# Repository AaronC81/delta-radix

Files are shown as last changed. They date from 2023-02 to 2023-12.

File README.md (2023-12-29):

# Delta Radix

**[Try it online!](https://aaronc81.github.io/delta-radix/)**

The Delta Radix is a desktop calculator designed specifically to be useful for binary and
hexadecimal calculations.

Notable features:

- Mixed binary, hexadecimal, and decimal calculations
- Customisable bit width of arithmetic type (not limited to powers of 2!)
- Support for signed and unsigned data types
- Accurate simulation of overflow 
- Mechanical keyswitches for input

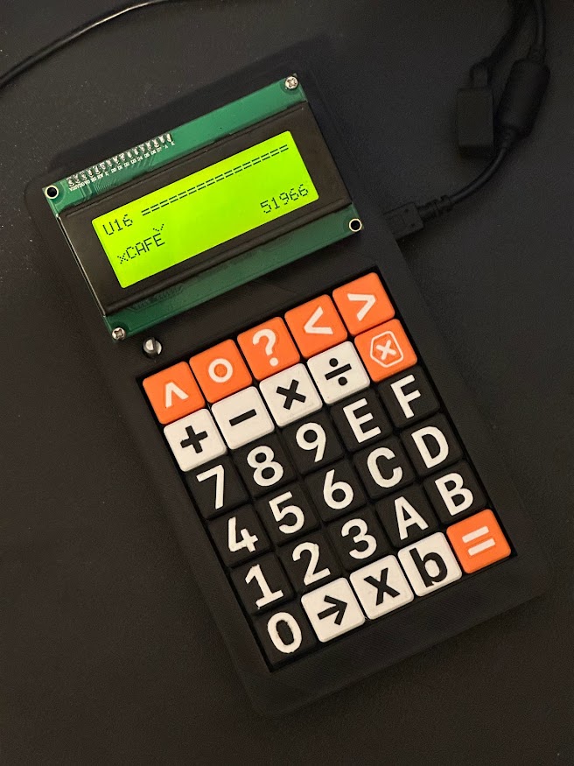
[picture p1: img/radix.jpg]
The Delta Radix calculator, assembled into a black 3D-printed case, with a mixture of black, white, and orange buttons. The black-on-green LCD display is showing the calculation "xCAFE", which evaluates to "51966" in decimal.


## Software

This repository is a Cargo workspace comprising a handful of crates. These are:

- `delta-radix-os` - The user-facing calculator software, 100% hardware-agnostic
- `delta-radix-hal` - Traits which the OS uses to interact with hardware (keypad, display, etc)
- `delta-radix-hal-pico` - Implementation of HAL traits for the Raspberry Pi Pico
- `delta-radix-hal-sim` - Implementation of HAL traits for a simulator which runs in the terminal
- `delta-radix-hal-web` - Implementation of HAL traits for a browser-based simulator with WebAssembly
  (build with `wasm-pack build --target web`, then visit `index.html`)
- `flex-int` - Arbitrary-precision arithmetic library used by the OS

The HAL implementations are the executable targets which should be flashed/run.

Elsewhere, you'll also find:

- [`delta-radix-numworks`](https://github.com/AaronC81/delta-radix-numworks) - Implementation of HAL
  traits for an app on the NumWorks graphing calculator.
  - This is a separate repository because it's not a pure-Cargo project, rather a Rust static
    library linked against a supporting C binary.

## Hardware

`hardware/` contains a KiCad schematic and PCB design.

`cad/` contains a 3D-printable case which the PCB can be mounted into, and keycaps for the switches.

## Usage

**Note:** Arithmetic parsing is incomplete! While they are implemented in the arithmetic library,
there's no way to input operations other than addition yet.

Base specifiers can appear on either site of a number (`xCAFE` or `CAFEx`), whichever you prefer. A
number without a base specifier is always interpreted as a decimal.

To change the result base, press the Format Select (`->`) key and then the base you'd like. Press
the Format Select key twice to return to decimal.

To change the arithmetic data type, use the Menu key. Enter a number of bits, and use the `+`/`-`
keys to choose signed or unsigned respectively.

Shift > Menu shows a menu of meta options, such as entering the bootloader.

## Things left to do

- [X] Faster parsing mode for constant overflow warnings
  - Parsing is slow, largely because of `FlexInt::from_unsigned_decimal_string` 
  - Wouldn't be a problem for evaluation, but is annoying during editing (key-press lag)
  - Either add a faster overall parsing mode just for constant overflow warnings, or versions of 
    number parsing which aren't suitable for evaluation but are fine for warnings (e.g. just use
    built-in Rust parsing, don't calculate overflow)
- [X] "Clear" key (shift + del?)
- [ ] Variables
- [X] Parentheses
- [X] Scrolling expression input
- [X] Show result as if unsigned
- [X] Sleep after inactivity

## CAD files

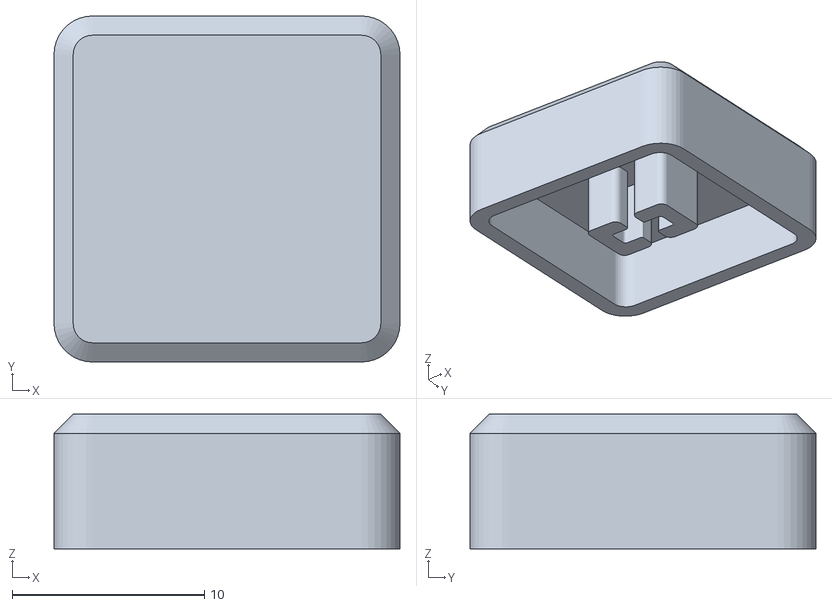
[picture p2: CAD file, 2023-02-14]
cad/keycaps/keycap_base.stl
18.0 x 18.0 x 7.00

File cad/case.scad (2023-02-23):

module fillet(r) {
    difference() {
        square(r);
        translate([r, r]) circle(r, $fn=50);
    }
}

module fillet_corner(r) {
    difference() {
        cube(r);
        translate([r, r, r]) sphere(r, $fn=50);
    }
}

module case_fillets(r) {
    // Edge fillets
    translate([0, case_true_height, 0])
    rotate([90, 0, 0])
    linear_extrude(case_true_height)
    fillet(r);
    
    translate([case_width, case_true_height, 0])
    rotate([90, 270, 0])
    linear_extrude(case_true_height)
    fillet(r);
   
    translate([case_width, 0, 0])
    rotate([0, -90, 0])
    linear_extrude(case_width)
    fillet(r);
    
    translate([case_width, case_true_height, 0])
    rotate([90, 0, 0])
    rotate([0, -90, 0])
    linear_extrude(case_width)
    fillet(r);
    
    // Fillet corners
    fillet_corner(r);
    
    translate([case_width, 0]) rotate([0, 0, 90])
    fillet_corner(r);
    
    translate([case_width, case_true_height]) rotate([0, 0, 180])
    fillet_corner(r);
    
    translate([0, case_true_height]) rotate([0, 0, 270])
    fillet_corner(r);
}

// --------------

calc_width = 100.75 + 0.2;
calc_height = 159.12 + 0.75;

calc_mounting_hole_offset = 4;
calc_mounting_hole_diameter = 2.6; // about right for m3
calc_mounting_hole_depth = 6;

calc_usb_port_from_bottom = 137; // distance to CENTRE
calc_usb_port_width = 15; // be generous for tolerances and/or big cables

calc_mounting_hole_locations = [
    [0, 0],
    [calc_width - calc_mounting_hole_offset * 2, 0],
    [0, calc_height - calc_mounting_hole_offset * 2],
    [calc_width - calc_mounting_hole_offset * 2, calc_height - calc_mounting_hole_offset * 2],
];

calc_pcb_thickness = 1.65;
calc_underneath_thickness = 2.75;

module calc_cutout() {
    translate([0, 0, calc_mounting_hole_depth - calc_underneath_thickness]) {
        difference() {
            linear_extrude(calc_pcb_thickness + calc_underneath_thickness)
            square([calc_width, calc_height]);

            for (loc = calc_mounting_hole_locations) {
                linear_extrude(calc_underneath_thickness)
                translate(loc)
                square([calc_mounting_hole_offset * 2, calc_mounting_hole_offset * 2]);
            }
        }

        for (loc = calc_mounting_hole_locations) {
            translate(concat(loc + [calc_mounting_hole_offset, calc_mounting_hole_offset], -calc_mounting_hole_depth + calc_underneath_thickness))
            linear_extrude(calc_mounting_hole_depth)
            circle(d = calc_mounting_hole_diameter, $fn = 20);
        }
    }
}

calc_cutout_total_thickness = calc_pcb_thickness + calc_mounting_hole_depth;

// ------------


display_mounting_hole_sep_y = 54.5;
display_mounting_hole_sep_x = 93;
display_mounting_hole_diameter = calc_mounting_hole_diameter;

display_post_width = 8;

display_board_width = 98;
display_board_height = 60;

display_tilt_angle = 15;
display_min_height = 7;

display_pin_cutout_width = 45;
display_pin_cutout_height = 5.5;

display_centre_cutout_width = display_board_width - 14;
display_centre_cutout_height = 48;

module display_frame() {
    difference() {
        rotate([display_tilt_angle, 0])
        translate([0, 0, -20]) // arbitrary
        linear_extrude(20 + display_min_height) // arbitrary
        difference() {
            square([display_board_width, display_board_height]);
            
            // Mounting holes
            translate([display_board_width / 2, display_board_height / 2]) {
                for (mul = [[1, 1], [-1, 1], [1, -1], [-1, -1]]) {
                    translate([display_mounting_hole_sep_x * mul[0] / 2, display_mounting_hole_sep_y * mul[1] / 2])
                    circle(d = case_mounting_hole_diameter, $fn = 20);
                }
                
                translate([-display_centre_cutout_width/2, -display_centre_cutout_height/2])
                square([display_centre_cutout_width, display_centre_cutout_height]);
            }
            
            // Pins
            translate([7, display_board_height - display_pin_cutout_height - 0.5])
            square([display_pin_cutout_width, display_pin_cutout_height]);
        }
        
        // All arbitrary, to cut off the bottom
        translate([0, 0, -100])
        linear_extrude(100)
        square([100, 100]);
    }
}

// ------------

case_height = 200;
case_mounting_hole_offset = 5.5;
case_mounting_hole_diameter = 2.6; // about right for m3

bottom_case_mounting_hole_guide_depth = 6;
bottom_case_mounting_hole_guide_diameter = 6;
bottom_case_calc_border = 8;
bottom_case_depth = 2; // not excluding the height of the PCB
bottom_case_true_depth = calc_cutout_total_thickness + bottom_case_depth;

case_width = calc_width + bottom_case_calc_border * 2;
case_true_height = case_height + bottom_case_calc_border * 2;

bottom_case_logo_indent = 2.5;
bottom_case_fillet_radius = 10;

case_mounting_hole_locations = [
    [0, 0],
    [case_width - case_mounting_hole_offset * 2, 0],
    [0, case_true_height - case_mounting_hole_offset * 2],
    [case_width - case_mounting_hole_offset * 2, case_true_height - case_mounting_hole_offset * 2],
];

module logo() {
    translate([-60 / 2, 3 - 50 / 2])
    minkowski() {
        polygon([
            [0, 0],
            [30, 50],
            [60, 0],
            [0, 0.1],
            [60, 0.1],
            [30, 50.1],
            [0, 0.1]
        ]);
        circle(4, $fn=30);
    }
}

module bottom_case() {
    difference() {
        linear_extrude(calc_cutout_total_thickness + bottom_case_depth)
        minkowski() {
            translate([bottom_case_calc_border, bottom_case_calc_border])
            square([calc_width, case_height]);
            
            circle(r = bottom_case_calc_border, $fn = 20);
        }
        
        translate([bottom_case_calc_border, bottom_case_calc_border, bottom_case_depth])
        calc_cutout();
        
        for (loc = case_mounting_hole_locations) {
            translate(loc + [case_mounting_hole_offset, case_mounting_hole_offset])
            linear_extrude(1000) // arbitrary
            circle(d = case_mounting_hole_diameter, $fn = 20);
            
            translate(loc + [case_mounting_hole_offset, case_mounting_hole_offset])
            linear_extrude(bottom_case_mounting_hole_guide_depth)
            circle(d = bottom_case_mounting_hole_guide_diameter, $fn = 20);
        }
        
        translate([bottom_case_calc_border + calc_width, bottom_case_calc_border + calc_usb_port_from_bottom - calc_usb_port_width / 2])
        linear_extrude(100) // arbitrary
        square([bottom_case_calc_border, calc_usb_port_width]);
        
        translate([case_width / 2, case_true_height / 2])
        linear_extrude(bottom_case_logo_indent)
        logo();
        
        case_fillets(bottom_case_fillet_radius);
    }
    
}

// All from the edge of the PCB, not the case
top_case_button_padding_horizontal = 2;
top_case_button_padding_bottom = 7.6;
top_case_button_padding_top = 36; // TODO: needs pot cutout

top_case_mounting_hole_depth = 5;
top_case_rim_depth = 18.3; // should be roughly around the top of keys

top_case_rim_overhang_spacing = 10; // amount of depth until overhangs for key padding

top_case_pot_x = 12.32; // from left
top_case_pot_y = 28.85; // from top
top_case_pot_diameter = 8;

top_case_reset_button_distance_x = 18;
top_case_reset_button_width = 4.3;
top_case_reset_button_height = 3.5;
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

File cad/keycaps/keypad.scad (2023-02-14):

keycap_height = 7;
legend_height = 1.5;
keycap_size = 18;
legend_font_size = 14;

module keycap_with_legend(txt, legend_y_offset=0, legend_x_offset=0) {
    difference() {
        import("keycap_base.stl");

        translate([keycap_size / 2 - .25 + legend_x_offset, (keycap_size - legend_font_size) / 2 + legend_y_offset, keycap_height - legend_height])
        legend(txt, legend_height);
    }
}

module legend(txt, height) {
    linear_extrude(height)
    offset(delta = -0.1)
    text(txt, size = legend_font_size, halign = "center", font = "SF Mono:style=Bold");
}

// ------------------

module number_and_letter_keycaps() {
    s = 25;

    translate([s*0, s*0]) keycap_with_legend("O");

    translate([s*0, s*1]) keycap_with_legend("1");
    translate([s*1, s*1]) keycap_with_legend("2");
    translate([s*2, s*1]) keycap_with_legend("3");

    translate([s*0, s*2]) keycap_with_legend("4");
    translate([s*1, s*2]) keycap_with_legend("5");
    translate([s*2, s*2]) keycap_with_legend("6");

    translate([s*0, s*3]) keycap_with_legend("7");
    translate([s*1, s*3]) keycap_with_legend("8");
    translate([s*2, s*3]) keycap_with_legend("9");

    translate([s*1, s*0]) keycap_with_legend("A");
    translate([s*2, s*0]) keycap_with_legend("B");
    translate([s*3, s*0]) keycap_with_legend("C");
    translate([s*3, s*1]) keycap_with_legend("D");
    translate([s*3, s*2]) keycap_with_legend("E");
    translate([s*3, s*3]) keycap_with_legend("F");
}

module number_and_letter_legends() {
    s = 18;
    h = legend_height - 0.2;
    
    translate([s*0, s*0]) legend("O", h);

    translate([s*0, s*1]) legend("1", h);
    translate([s*1, s*1]) legend("2", h);
    translate([s*2, s*1]) legend("3", h);

    translate([s*0, s*2]) legend("4", h);
    translate([s*1, s*2]) legend("5", h);
    translate([s*2, s*2]) legend("6", h);

    translate([s*0, s*3]) legend("7", h);
    translate([s*1, s*3]) legend("8", h);
    translate([s*2, s*3]) legend("9", h);

    translate([s*1, s*0]) legend("A", h);
    translate([s*2, s*0]) legend("B", h);
    translate([s*3, s*0]) legend("C", h);
    translate([s*3, s*1]) legend("D", h);
    translate([s*3, s*2]) legend("E", h);
    translate([s*3, s*3]) legend("F", h);
}

// ------------------

module operator_keycaps() {
    s = 25;

    translate([s*0, s*0]) keycap_with_legend("+", 1);
    translate([s*1, s*0]) keycap_with_legend("−", 1);
    translate([s*2, s*0]) keycap_with_legend("×", 1);
    translate([s*3, s*0]) keycap_with_legend("÷", 1);
    
    translate([s*0, s*1]) keycap_with_legend("x", 1.7);
    translate([s*1, s*1]) keycap_with_legend("b", 0);
    translate([s*2, s*1]) keycap_with_legend("→", 0, 0.3);
}

module operator_legends() {
    s = 18;
    h = legend_height - 0.2;

    translate([s*0, s*0]) legend("+", h);
    translate([s*1, s*0]) legend("−", h);
    translate([s*2, s*0]) legend("×", h);
    translate([s*3, s*0]) legend("÷", h);
    
    translate([s*0, s*1]) legend("x", h);
    translate([s*1, s*1]) legend("b", h);
    translate([s*2, s*1]) legend("→", h);
}

// ------------------

// TODO
module special_keycaps() {
    s = 25;

    translate([s*0, s*0]) keycap_with_legend("^", -3); // Shift
    translate([s*2, s*1]) keycap_with_legend("=", 1);  // Exe
    translate([s*1, s*0]) keycap_with_legend("◦", 1);  // Menu

    translate([s*0, s*1]) keycap_with_legend("<", 1);  // Left
    translate([s*1, s*1]) keycap_with_legend(">", 1);  // Right
    
    translate([s*2, s*0]) keycap_with_legend("⌫", 0);  // Del
    
    translate([s*3, s*0]) keycap_with_legend("?", 0);  // Var
}

module special_legends() {
    s = 18;
    h = legend_height - 0.2;

    //translate([s*0, s*0]) legend("^", h); // Shift
    //translate([s*2, s*1]) legend("=", h);  // Exe
    //translate([s*1, s*0]) legend("◦", h);  // Menu

    translate([s*0, s*1]) legend("<", h);  // Left
    translate([s*1, s*1]) legend(">", h);  // Right
    
    //translate([s*2, s*0]) legend("⌫", h);  // Del
    
    //translate([s*3, s*0]) legend("?", h);  // Var
}

special_legends();

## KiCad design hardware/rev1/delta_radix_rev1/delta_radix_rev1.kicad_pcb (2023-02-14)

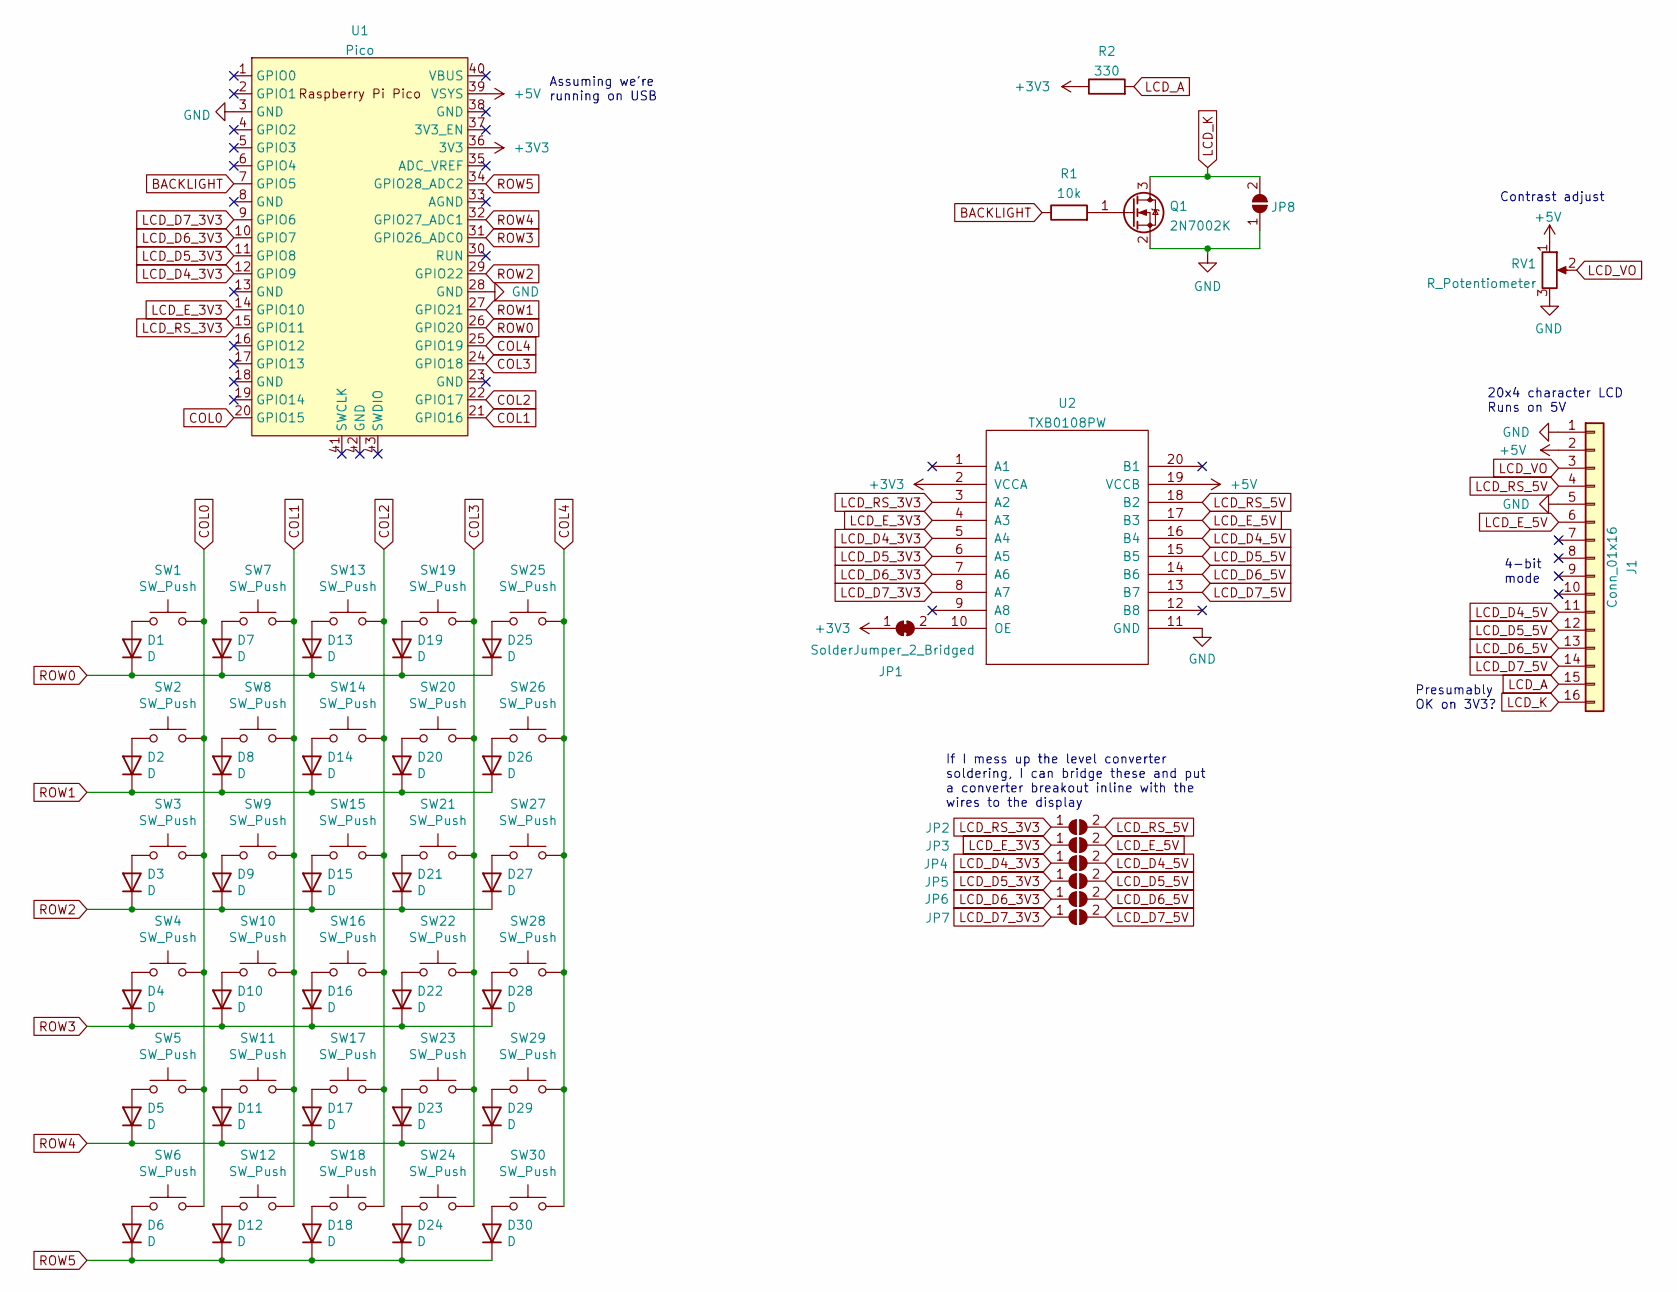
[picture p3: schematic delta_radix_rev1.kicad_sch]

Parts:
D1, D2, D3, D4, D5, D6, D7, D8, D9, D10, D11, D12, D13, D14, D15, D16, D17, D18, D19, D20, D21, D22, D23, D24, D25, D26, D27, D28, D29, D30: D; D_SOD-123
J1: Conn_01x16; PinHeader_1x16_P2.54mm_Vertical
JP1: SolderJumper_2_Bridged; SolderJumper-2_P1.3mm_Bridged_RoundedPad1.0x1.5mm
JP2, JP3, JP4, JP5, JP6, JP7, JP8: SolderJumper_2_Open; SolderJumper-2_P1.3mm_Open_RoundedPad1.0x1.5mm
Q1: 2N7002K; SOT-23_Handsoldering
R1: 10k; R_0603_1608Metric_Pad0.98x0.95mm_HandSolder
R2: 330; R_0603_1608Metric_Pad0.98x0.95mm_HandSolder
RV1: R_Potentiometer; Potentiometer_Alpha_RD901F-40-00D_Single_Vertical_CircularH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
SW1, SW2, SW3, SW4, SW5, SW6, SW7, SW8, SW9, SW10, SW11, SW12, SW13, SW14, SW15, SW16, SW17, SW18, SW19, SW20, SW21, SW22, SW23, SW24, SW25, SW26, SW27, SW28, SW29, SW30: SW_Push; SW_Cherry_MX_1.00u_PCB
U1: Pico; RPi_Pico_SMD_TH
U2: TXB0108PW; TSSOP-20_4.4x6.5mm_P0.65mm

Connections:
+3V3: JP1.1 (A), R2.1, U1.36 (3V3), U2.2 (VCCA)
+5V: J1.2, RV1.1, U1.39 (VSYS), U2.19 (VCCB)
BACKLIGHT: R1.1, U1.7 (GPIO5)
COL0: SW1.2, SW2.2, SW3.2, SW4.2, SW5.2, SW6.2, U1.20 (GPIO15)
COL1: SW7.2, SW8.2, SW9.2, SW10.2, SW11.2, SW12.2, U1.21 (GPIO16)
COL2: SW13.2, SW14.2, SW15.2, SW16.2, SW17.2, SW18.2, U1.22 (GPIO17)
COL3: SW19.2, SW20.2, SW21.2, SW22.2, SW23.2, SW24.2, U1.24 (GPIO18)
COL4: SW25.2, SW26.2, SW27.2, SW28.2, SW29.2, SW30.2, U1.25 (GPIO19)
GND: J1.1, J1.5, JP8.1 (A), Q1.2 (S), RV1.3, U1.3 (GND), U1.28 (GND), U2.11 (GND)
LCD_A: J1.15, R2.2
LCD_D4_3V3: JP4.1 (A), U1.12 (GPIO9), U2.5 (A4)
LCD_D4_5V: J1.11, JP4.2 (B), U2.16 (B4)
LCD_D5_3V3: JP5.1 (A), U1.11 (GPIO8), U2.6 (A5)
LCD_D5_5V: J1.12, JP5.2 (B), U2.15 (B5)
LCD_D6_3V3: JP6.1 (A), U1.10 (GPIO7), U2.7 (A6)
LCD_D6_5V: J1.13, JP6.2 (B), U2.14 (B6)
LCD_D7_3V3: JP7.1 (A), U1.9 (GPIO6), U2.8 (A7)
LCD_D7_5V: J1.14, JP7.2 (B), U2.13 (B7)
LCD_E_3V3: JP3.1 (A), U1.14 (GPIO10), U2.4 (A3)
LCD_E_5V: J1.6, JP3.2 (B), U2.17 (B3)
LCD_K: J1.16, JP8.2 (B), Q1.3 (D)
LCD_RS_3V3: JP2.1 (A), U1.15 (GPIO11), U2.3 (A2)
LCD_RS_5V: J1.4, JP2.2 (B), U2.18 (B2)
LCD_VO: J1.3, RV1.2
unnamed: D1.2 (A), SW1.1
unnamed: D2.2 (A), SW2.1
unnamed: D3.2 (A), SW3.1
unnamed: D4.2 (A), SW4.1
unnamed: D5.2 (A), SW5.1
unnamed: D6.2 (A), SW6.1
unnamed: D7.2 (A), SW7.1
unnamed: D8.2 (A), SW8.1
unnamed: D9.2 (A), SW9.1
unnamed: D10.2 (A), SW10.1
unnamed: D11.2 (A), SW11.1
unnamed: D12.2 (A), SW12.1
unnamed: D13.2 (A), SW13.1
unnamed: D14.2 (A), SW14.1
unnamed: D15.2 (A), SW15.1
unnamed: D16.2 (A), SW16.1
unnamed: D17.2 (A), SW17.1
unnamed: D18.2 (A), SW18.1
unnamed: D19.2 (A), SW19.1
unnamed: D20.2 (A), SW20.1
unnamed: D21.2 (A), SW21.1
unnamed: D22.2 (A), SW22.1
unnamed: D23.2 (A), SW23.1
unnamed: D24.2 (A), SW24.1
unnamed: D25.2 (A), SW25.1
unnamed: D26.2 (A), SW26.1
unnamed: D27.2 (A), SW27.1
unnamed: D28.2 (A), SW28.1
unnamed: D29.2 (A), SW29.1
unnamed: D30.2 (A), SW30.1
unnamed: JP1.2 (B), U2.10 (OE)
unnamed: Q1.1 (G), R1.2
ROW0: D1.1 (K), D7.1 (K), D13.1 (K), D19.1 (K), D25.1 (K), U1.26 (GPIO20)
ROW1: D2.1 (K), D8.1 (K), D14.1 (K), D20.1 (K), D26.1 (K), U1.27 (GPIO21)
ROW2: D3.1 (K), D9.1 (K), D15.1 (K), D21.1 (K), D27.1 (K), U1.29 (GPIO22)
ROW3: D4.1 (K), D10.1 (K), D16.1 (K), D22.1 (K), D28.1 (K), U1.31 (GPIO26_ADC0)
ROW4: D5.1 (K), D11.1 (K), D17.1 (K), D23.1 (K), D29.1 (K), U1.32 (GPIO27_ADC1)
ROW5: D6.1 (K), D12.1 (K), D18.1 (K), D24.1 (K), D30.1 (K), U1.34 (GPIO28_ADC2)

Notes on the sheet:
Contrast adjust
Presumably OK on 3V3?
4-bit mode
If I mess up the level converter soldering, I can bridge these and put a converter breakout inline with the wires to the display
20x4 character LCD Runs on 5V
Assuming we're running on USB

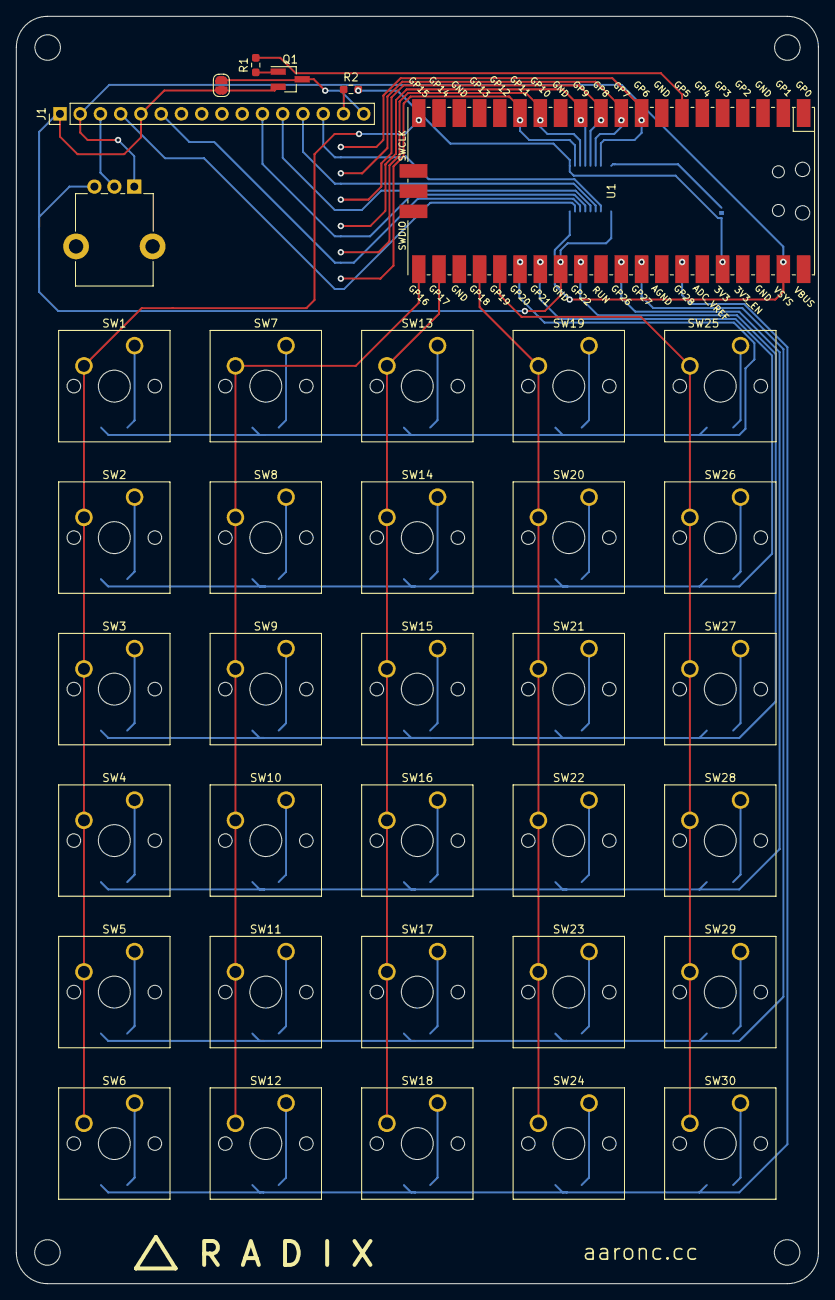
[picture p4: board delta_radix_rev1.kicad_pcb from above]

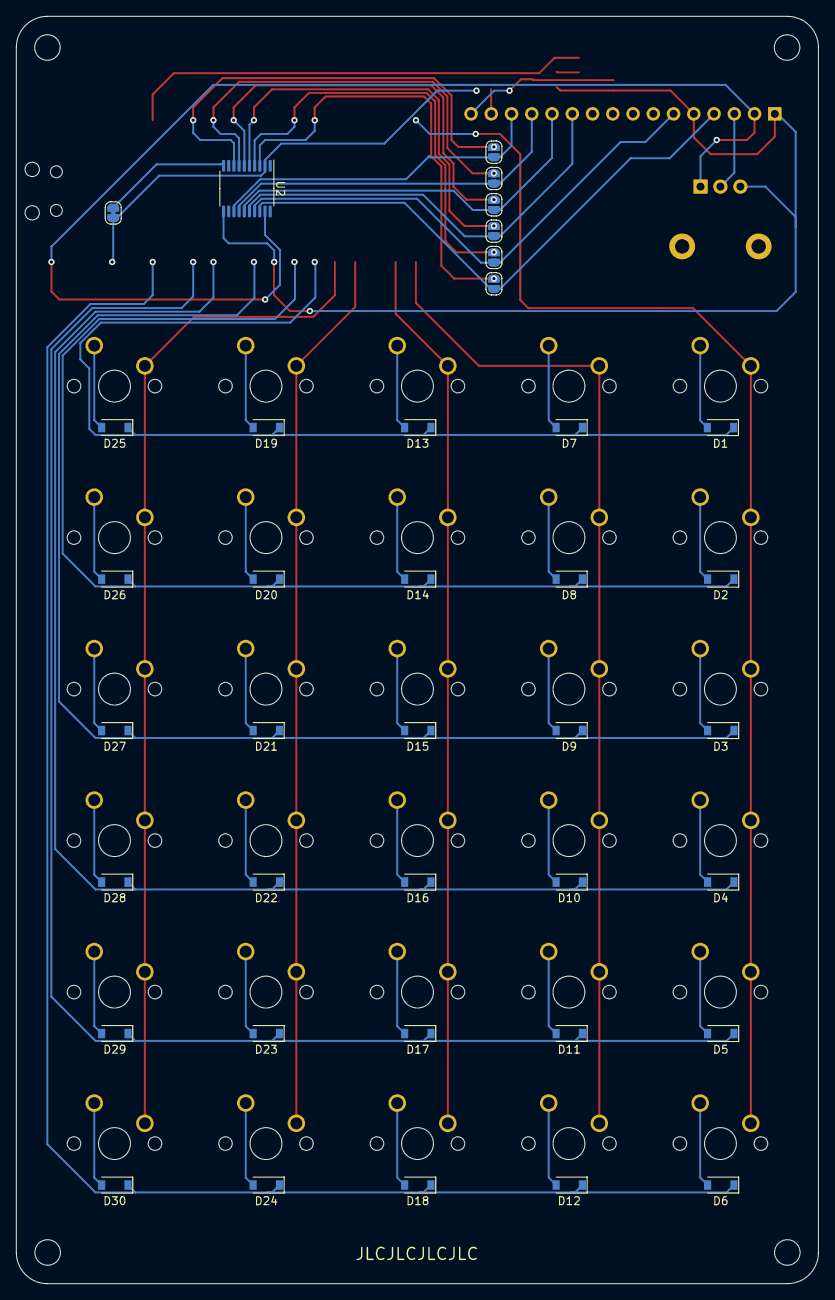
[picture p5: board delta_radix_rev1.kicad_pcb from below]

Board: 2 copper layers, 100.6 x 159.0 mm, 75 parts (38 on the bottom side), 62 nets.

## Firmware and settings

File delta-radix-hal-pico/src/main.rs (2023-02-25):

#![no_std]
#![no_main]
#![feature(alloc_error_handler)]
#![feature(generic_const_exprs)]
#![feature(async_fn_in_trait)]

use alloc_cortex_m::CortexMHeap;
use cortex_m_rt::entry;
use delta_radix_hal::Key;
use embedded_hal::digital::v2::OutputPin;
use hal::{PicoHal, async_keypad::{async_keypad_core1, AsyncKeypadReceiver, ASYNC_KEYPAD_START_MAGIC}};
use hd44780_driver::HD44780;
use panic::init_panic_hal;
use rp_pico::{hal::{Watchdog, Sio, clocks::init_clocks_and_plls, Clock, multicore::{Stack, Multicore}}, pac, Pins};
use embedded_time::{fixed_point::FixedPoint};

extern crate alloc;

mod hal;
mod panic;
mod executor;

fn lives_forever<T: ?Sized>(t: &mut T) -> &'static mut T {
    unsafe { (t as *mut T).as_mut().unwrap() }
}

#[global_allocator]
static ALLOCATOR: CortexMHeap = CortexMHeap::empty();
const HEAP_SIZE: usize = 230_000;

static mut CORE1_STACK: Stack<4096> = Stack::new();

#[entry]
fn main() -> ! {
    // Set up allocator
    {
        use core::mem::MaybeUninit;
        static mut HEAP: [MaybeUninit<u8>; HEAP_SIZE] = [MaybeUninit::uninit(); HEAP_SIZE];
        unsafe {
            ALLOCATOR.init(HEAP.as_ptr() as usize, HEAP_SIZE)
        }
    }

    let mut pac = pac::Peripherals::take().unwrap();
    let core = pac::CorePeripherals::take().unwrap();
    let mut watchdog = Watchdog::new(pac.WATCHDOG);
    let mut sio = Sio::new(pac.SIO);

    let mut mc = Multicore::new(&mut pac.PSM, &mut pac.PPB, &mut sio);
    let cores = mc.cores();
    let core1 = &mut cores[1];
    let _test = core1.spawn(async_keypad_core1, unsafe { &mut CORE1_STACK.mem });

    // External high-speed crystal on the pico board is 12Mhz
    let external_xtal_freq_hz = 12_000_000u32;
    let clocks = init_clocks_and_plls(
        external_xtal_freq_hz,
        pac.XOSC,
        pac.CLOCKS,
        pac.PLL_SYS,
        pac.PLL_USB,
        &mut pac.RESETS,
        &mut watchdog,
    )
        .ok()
        .unwrap();

    let mut delay = cortex_m::delay::Delay::new(core.SYST, clocks.system_clock.freq().integer());

    let pins = Pins::new(
        pac.IO_BANK0,
        pac.PADS_BANK0,
        sio.gpio_bank0,
        &mut pac.RESETS,
    );
    let mut led = pins.led.into_push_pull_output();

    let mut backlight = pins.gpio5.into_push_pull_output();
    backlight.set_high().unwrap();

    // const int rs = 11, en = 10, d4 = 9, d5 = 8, d6 = 7, d7 = 6;
    let rs = pins.gpio11.into_push_pull_output();
    let en = pins.gpio10.into_push_pull_output();
    let d4 = pins.gpio9.into_push_pull_output();
    let d5 = pins.gpio8.into_push_pull_output();
    let d6 = pins.gpio7.into_push_pull_output();
    let d7 = pins.gpio6.into_push_pull_output();
    
    let lcd = HD44780::new_4bit(rs, en, d4, d5, d6, d7, &mut delay).unwrap();

    let mut hal = PicoHal {
        display: hal::LcdDisplay { lcd, delay: lives_forever(&mut delay), backlight },
        keypad: AsyncKeypadReceiver {
            fifo: lives_forever(&mut sio.fifo),
        },
        time: hal::DelayTime { delay: lives_forever(&mut delay) },
    };
    init_panic_hal(lives_forever(&mut hal));

    // Tell the other core to get going
    sio.fifo.write(ASYNC_KEYPAD_START_MAGIC);    

    executor::execute(delta_radix_os::main(&mut hal));
    
    loop {
        led.set_high().unwrap();
        delay.delay_ms(1000);
        led.set_low().unwrap();
        delay.delay_ms(1000);
    }
}

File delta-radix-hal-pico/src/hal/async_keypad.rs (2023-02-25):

use delta_radix_hal::{Key, Keypad, Display};
use embedded_hal::digital::v2::OutputPin;
use embedded_time::duration::{Extensions, Duration, Seconds, Microseconds};
use rp_pico::{pac::{self, interrupt}, hal::{Sio, multicore::Stack, sio::SioFifo, timer::Alarm0, Timer}, Pins};

use crate::{lives_forever, executor, panic::get_panic_hal};

use super::ButtonMatrix;

pub struct AsyncKeypadReceiver<'s> {
    pub fifo: &'s mut SioFifo,
}

impl<'s> delta_radix_hal::Keypad for AsyncKeypadReceiver<'s> {
    async fn wait_key(&mut self) -> Key {
        let hal = get_panic_hal();

        loop {
            let message = self.fifo.read_blocking();

            if message == ASYNC_KEYPAD_SLEEP_MAGIC {
                hal.display.clear();
                hal.display.backlight.set_low().unwrap();

                return Key::Sleep;
            }

            if let Some(key) = Key::from_u32(message) {
                hal.display.backlight.set_high().unwrap();
                return key;
            }
        }
    }
}

pub const ASYNC_KEYPAD_START_MAGIC: u32 = 0xCAFECAFE;
pub const ASYNC_KEYPAD_SLEEP_MAGIC: u32 = 0x00BEDBED;

pub const SLEEP_TIME: Microseconds = Microseconds(120_000_000);

pub fn async_keypad_core1() -> ! {
    // Grab some important peripherals
    let mut pac = unsafe { pac::Peripherals::steal() };
    let core = unsafe { pac::CorePeripherals::steal() };
    let mut sio = Sio::new(pac.SIO);
    let mut delay = cortex_m::delay::Delay::new(core.SYST, 125_000_000);
    let pins = Pins::new(
        pac.IO_BANK0,
        pac.PADS_BANK0,
        sio.gpio_bank0,
        &mut pac.RESETS,
    );

    // Wait until the magic word over FIFO
    loop {
        if sio.fifo.read_blocking() == ASYNC_KEYPAD_START_MAGIC {
            break;
        }
    }

    // Set up button matrix
    let mut matrix = ButtonMatrix {
        delay: lives_forever(&mut delay),

        col0: pins.gpio15.into_pull_up_input(),
        col1: pins.gpio16.into_pull_up_input(),
        col2: pins.gpio17.into_pull_up_input(),
        col3: pins.gpio18.into_pull_up_input(),
        col4: pins.gpio19.into_pull_up_input(),

        row0: pins.gpio20.into_push_pull_output(),
        row1: pins.gpio21.into_push_pull_output(),
        row2: pins.gpio22.into_push_pull_output(),
        row3: pins.gpio26.into_push_pull_output(),
        row4: pins.gpio27.into_push_pull_output(),
        row5: pins.gpio28.into_push_pull_output(),

        currently_pressed: None,
    };

    // Set up timer stuff
    unsafe { pac::NVIC::unmask(pac::Interrupt::TIMER_IRQ_0); }
    let mut timer = Timer::new(pac.TIMER, &mut pac.RESETS);
    let mut alarm = timer.alarm_0().unwrap();
    
    // For the rest of time, loop looking for buttons
    loop {
        // Set up inactivity timer
        alarm.disable_interrupt();
        alarm.schedule(SLEEP_TIME).unwrap();
        alarm.enable_interrupt();
    
        // Wait for press
        let key = executor::execute(matrix.wait_key());
        sio.fifo.write(key.to_u32());
    }
}

#[interrupt]
fn TIMER_IRQ_0() {
    let mut pac = unsafe { pac::Peripherals::steal() };
    let mut sio = Sio::new(pac.SIO);

    // Let the other core know to put the display into a sleep state
    sio.fifo.write(ASYNC_KEYPAD_SLEEP_MAGIC);

    let mut timer = Timer::new(pac.TIMER, &mut pac.RESETS);
    let mut alarm = timer.alarm_0().unwrap();
    alarm.clear_interrupt();
}

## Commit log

2023-01-25 Add delta-radix-hal-pico project
2023-01-25 Implement basics of HAL for Pico
    Gets to a mangled version of the "Press a key" screen!
2023-01-27 Fix display position setting
    [hal.rs]
2023-01-27 "Fix" cursor appearance on hardware
    [display.rs]
2023-01-27 Add bootloader button
2023-01-30 Use own fork of hd44780-driver
2023-01-30 Init the screen correctly
    [display.rs]
2023-01-31 Exclude /cad until I've tidied it up a bit
2023-02-14 Add case models
    [case.scad, keycap_base.stl, keypad.scad]
2023-02-14 Add KiCad design
    [delta_radix_rev1.kicad_pcb, delta_radix_rev1.kicad_sch]
2023-02-15 Attempt to bind HAL to JS functions
    Fails to compile right now for some reason!
    [hal.rs]
2023-02-15 All buttons, and *style*
2023-02-16 Fix some clippy lints
    [hal.rs]
2023-02-16 Fix rust-analyser error, fix more warnings
    [main.rs]
2023-02-17 Better parse error messages
    [display.rs]
2023-02-18 Add a cleaner way of doing keys, new test case
2023-02-21 Fillets, tolerance tweaks, and logo for bottom case
    [case.scad]
2023-02-22 Add fillet to top case
    [case.scad]
2023-02-22 Add reset button hole
    [case.scad]
2023-02-22 Cut out chunk around the display to save filament
    [case.scad]
2023-02-22 Re-enable multicore with smaller heap
    Seems to magically fix things!
    [main.rs]
2023-02-23 Use new executor, wait for special message before starting
    I've figured out where the problem is, at least...
    (Because I can now see the panic message!)
    alloc-cortex-m uses `RefCell`s so we can't alloc in two cores simultaneously
    It's not trivial to remove allocations because `async_trait` desugars to `Box<Pin<...>>`
    Might need a different allocator :(
    [async_keypad.rs, main.rs]
2023-02-23 Use nightly async traits, with no box allocation - now working!
    Also changed a heap pin to a stack pin in async_keypad.rs
    Still need to migrate other HAL crates over to native async traits
2023-02-23 Add BOOTSEL pusher
    [case.scad]
2023-02-23 Fix tests by adding async_fn_in_trait attribute
    [hal.rs]
2023-02-25 Shift+0 to insert parens
    Don't parse yet
2023-02-25 Use * instead of unicode multiply for glyph print default
    So it's only one byte
2023-02-25 Add multiply symbol for Pico
2023-02-25 Add result-signedness override (currently not user-controllable)
2023-08-30 Use infallible align algorithm which supports non-powers-of-2
2023-09-07 Fix align insertion
